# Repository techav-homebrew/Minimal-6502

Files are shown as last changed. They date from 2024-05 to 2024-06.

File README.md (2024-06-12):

# Minimal-6502
Minimal 6502 SBC based on Grant Searle's 8-chip 6502 computer and laid out as a 4x3" PCB.

Modifications from Grant Searle's design include:
- Addition of expansion header
- Changed clock from crystal to standard TTL can oscillator
- Added option for USB for serial & power via FTDI
- Reassembled software for 8kB EEPROM instead of 16kB EPROM because 27128 EPROM is not readily available (PCB still supports 27128)

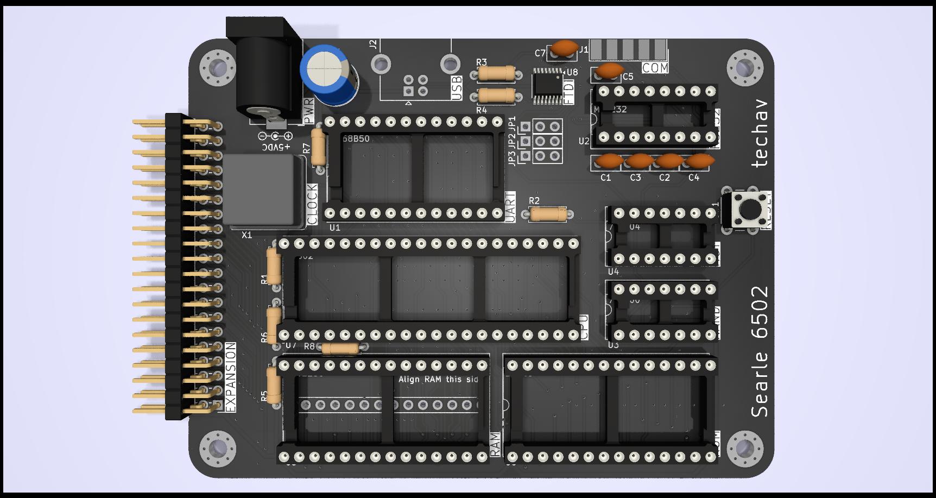
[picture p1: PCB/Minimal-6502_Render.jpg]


## Assembly Notes
Part U5, 32kB SRAM, can be either a 7.5mm or 14.5mm width part. If using a 7.5mm package, it should be aligned as indicated on the side closest to the CPU. 

Computer can be assembled with either an RS-232 serial port for use with a traditional terminal or USB serial adapter for use with a modern computer as a terminal. Parts related to each option are listed below.

### RS-232 DE-9 Serial
- J1 - DE-9 connector
- U2 - MAX232 RS-232 level shifter
- C1, C2, C3, C4 - 100nF capacitor
- J3 - 2.1mm barrel power connector

### USB Serial
- J2 - USB-B connector
- U8 - FTDI FT230X
- R3, R4 - 26-Ohm resistor

## Usage Notes
The computer should be powered by USB or via the barrel connector, not both. There is no on-board voltage regulation, so if the barrel connector is used, then the computer should be powered by a regulated 5V power supply. 

Serial bit rate is 115200, and backspace should be configured for **Control-H** (PuTTY defaults to **Control-?**)

When using a terminal emulator via USB, it may be necessary to press Reset to display the Cold Start prompt. 

If no size is entered on the memory size prompt, then the computer will attempt to determine the installed memory size.

## Expansion Port Header Pinout
1. +5V
2. +5V
3. +5V
4. +5V
5. D0
6. A0
7. D1
8. A1
9. D2
10. A2
11. D3
12. A3
13. D4
14. A4
15. D5
16. A5
17. D6
18. A6
19. D7
20. A7
21. R/W#
22. A8
23. READ#
24. A9
25. WRITE#
26. A10
27. NMI#
28. A11
29. RDY
30. A12
31. IRQ#
32. A13
33. [Not Connected]
34. A14
35. Phi2
36. A15
37. Ground
38. Ground
39. Ground
40. Ground

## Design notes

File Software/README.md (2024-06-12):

The contents of this folder were downloaded from http://searle.x10host.com/6502/Simple6502.html

utility bin2hex from https://www.sydneysmith.com/wordpress/bin2hex/

CHANGELOG
2024/06/11 techav:
- modified osi_bas.s & osi_bas.cfg for 8kB ROM (28C64) instead of 16kB ROM (27128) because the latter is harder to find these days.
- added bin2hex step to assemble.bat to generate Intel Hex file from assembled binary

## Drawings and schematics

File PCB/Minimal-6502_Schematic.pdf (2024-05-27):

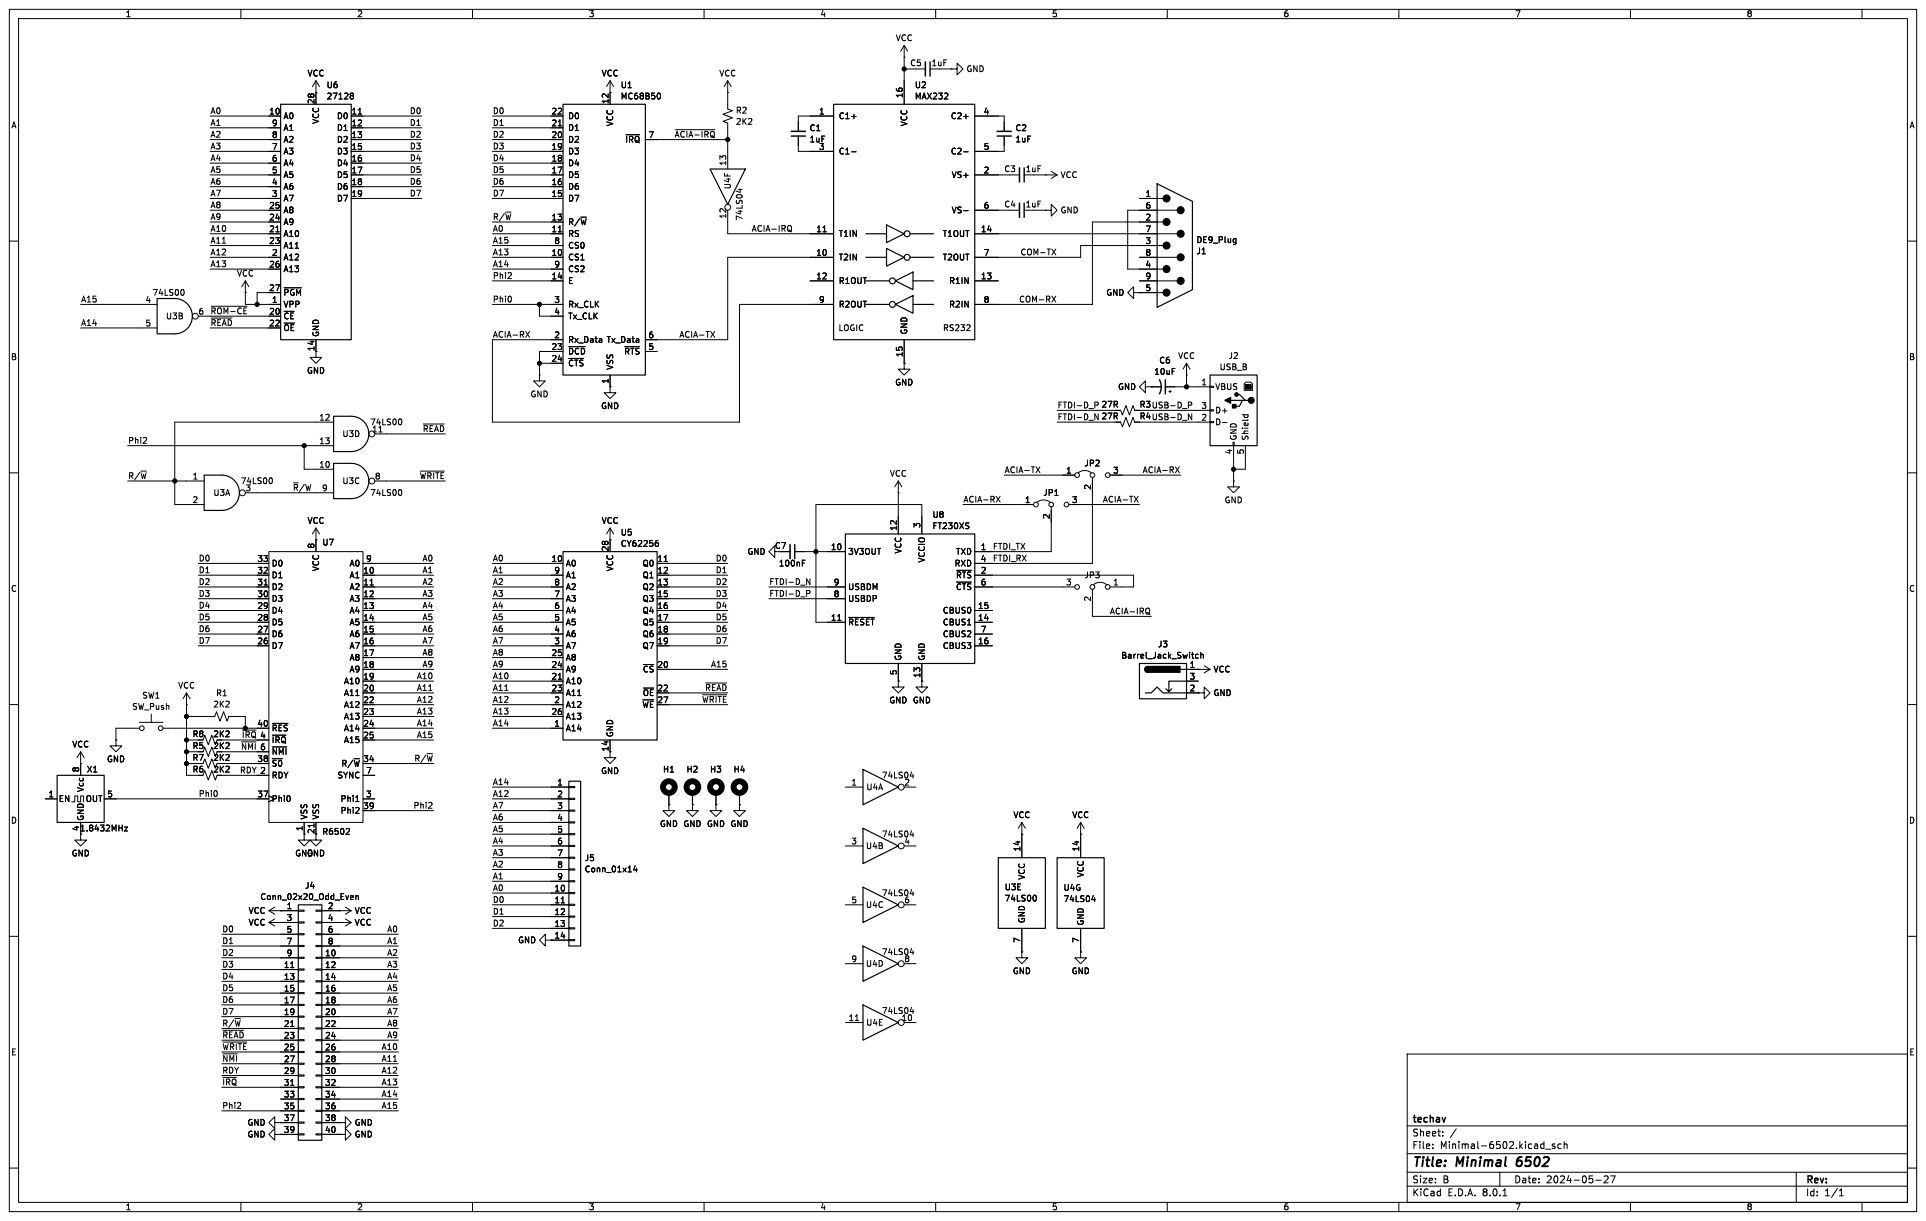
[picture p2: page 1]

COM-RX COM-TX

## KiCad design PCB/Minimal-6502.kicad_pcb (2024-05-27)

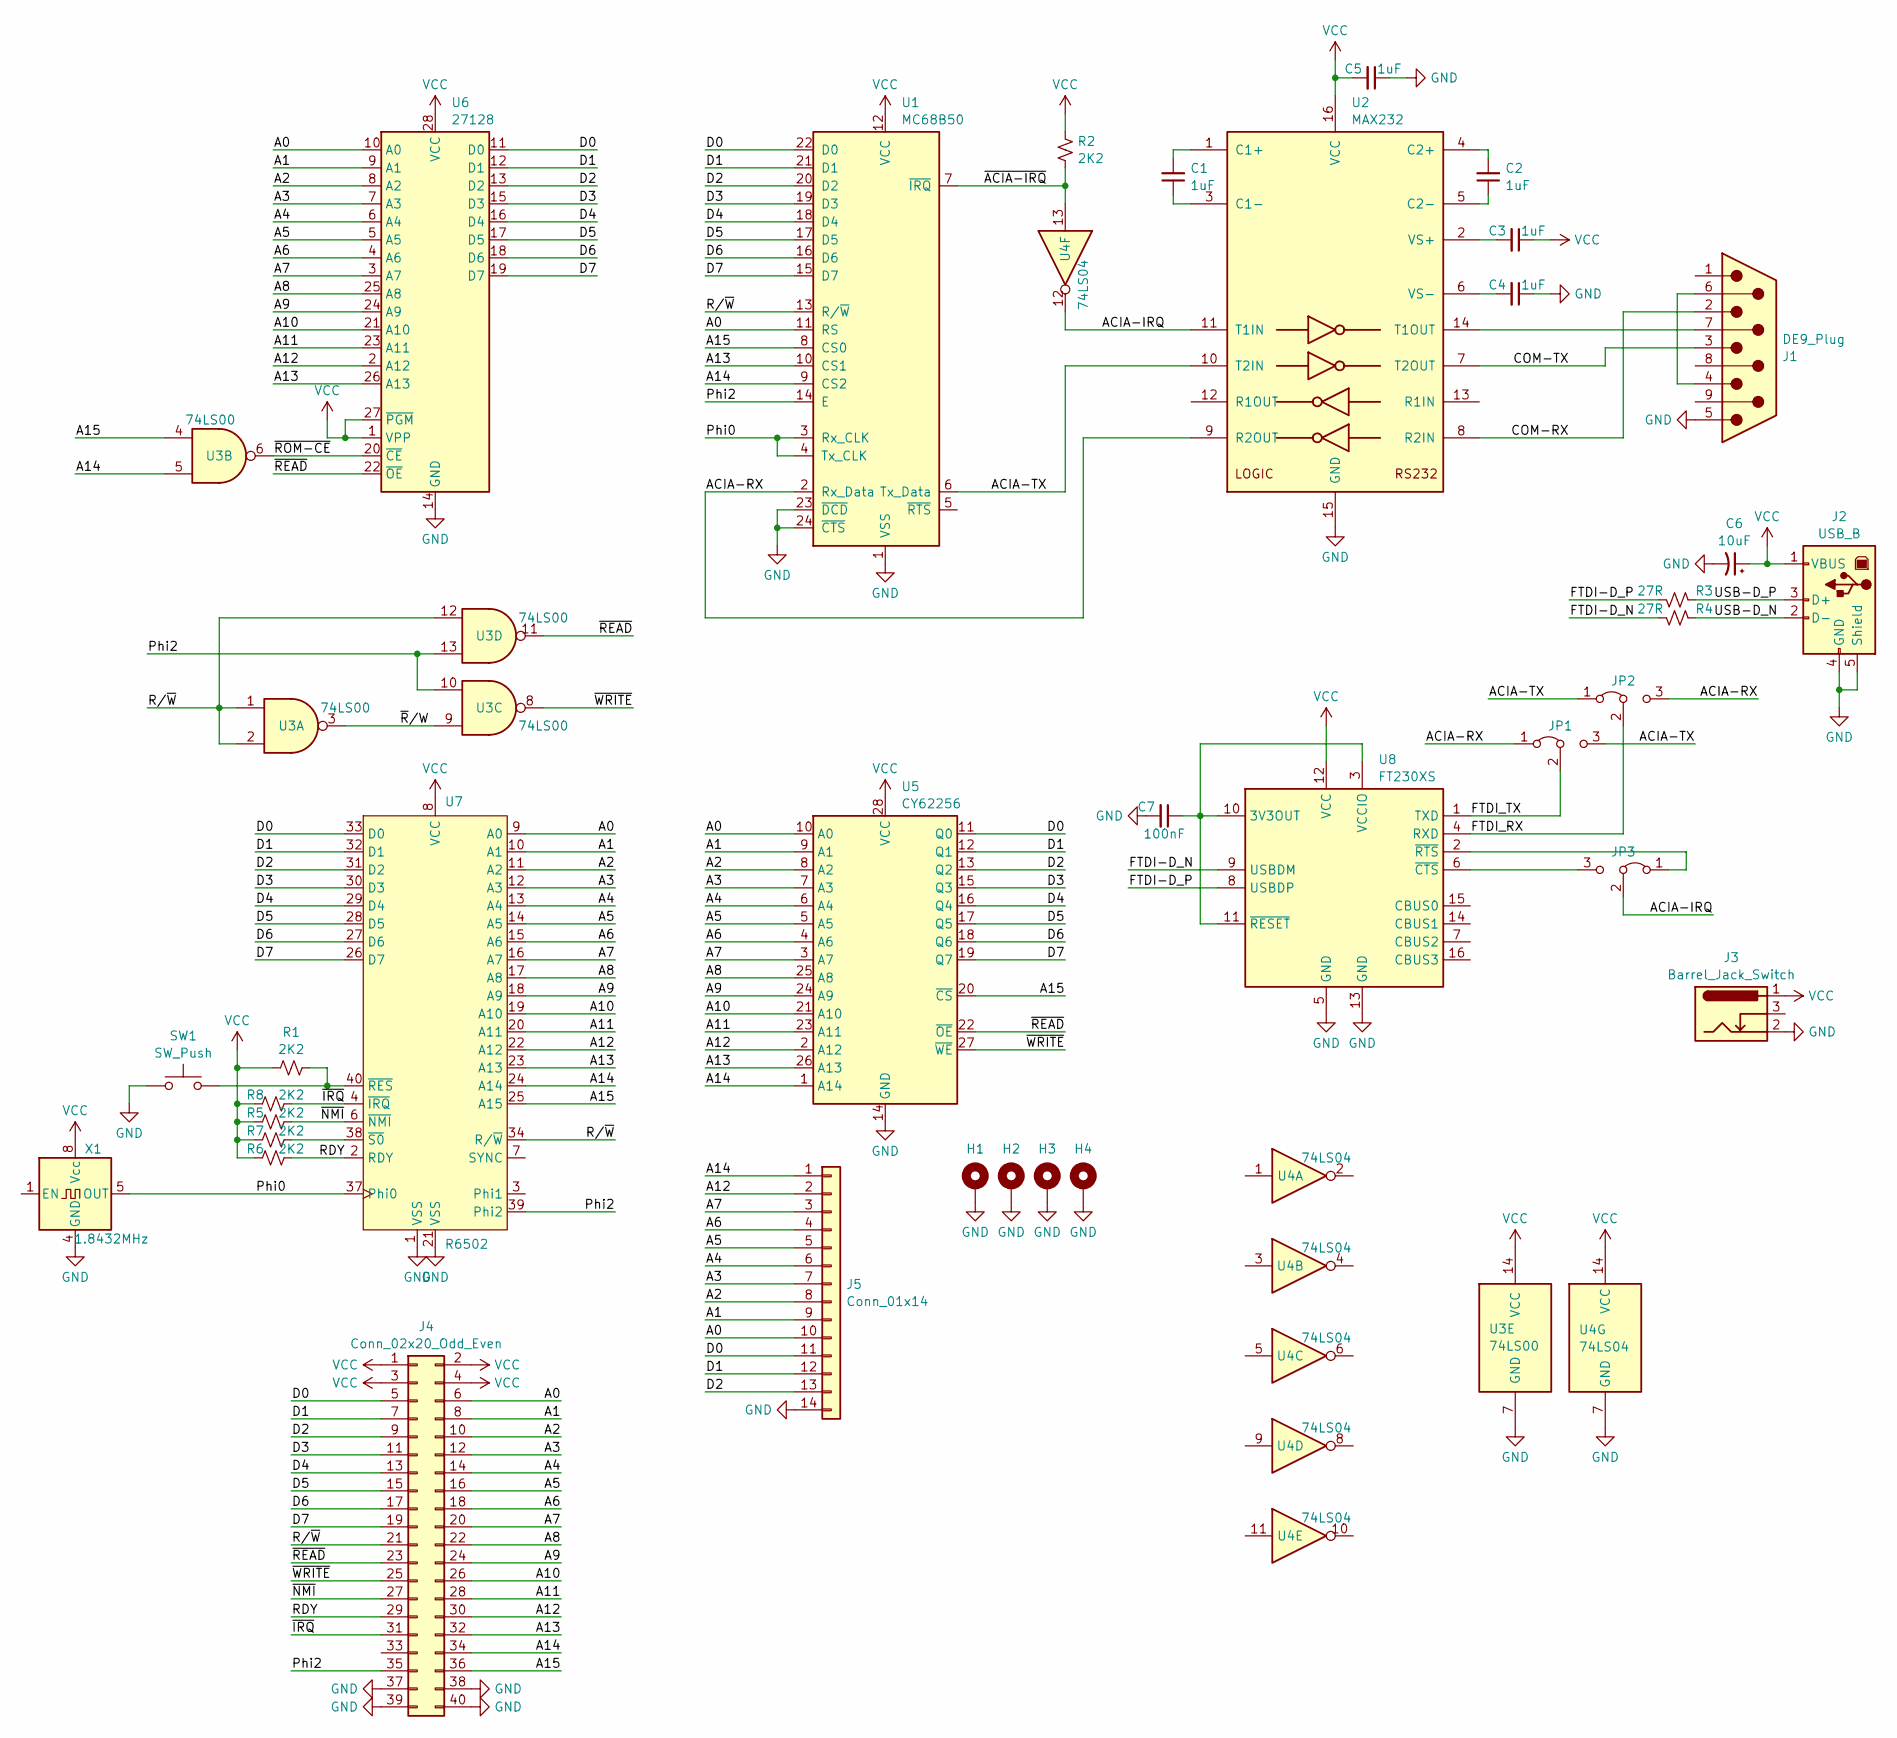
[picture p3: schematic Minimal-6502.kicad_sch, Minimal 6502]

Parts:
C1, C2, C3, C4, C5: 1uF; C_Disc_D5.0mm_W2.5mm_P2.50mm
C6: 10uF; CP_Radial_D8.0mm_P5.00mm
C7: 100nF; C_Disc_D5.0mm_W2.5mm_P2.50mm
H1, H2, H3, H4: MountingHole_Pad; MountingHole_3.2mm_M3_Pad_Via
J1: DE9_Plug; DSUB-9_Male_EdgeMount_P2.77mm
J2: USB_B; USB_B_OST_USB-B1HSxx_Horizontal
J3: Barrel_Jack_Switch; BarrelJack_Horizontal
J4: Conn_02x20_Odd_Even; PinHeader_2x20_P2.54mm_Horizontal
J5: Conn_01x14; PinHeader_1x14_P2.54mm_Vertical
JP1, JP2, JP3: Jumper_3_Bridged12; PinHeader_1x03_P2.54mm_Vertical
R1, R2, R5, R6, R7, R8: 2K2; R_Axial_DIN0207_L6.3mm_D2.5mm_P7.62mm_Horizontal
R3, R4: 27R; R_Axial_DIN0207_L6.3mm_D2.5mm_P7.62mm_Horizontal
SW1: SW_Push; SW_PUSH_6mm
U1: MC68B50; DIP-24_W15.24mm_Socket
U2: MAX232; DIP-16_W7.62mm_Socket
U3: 74LS00; DIP-14_W7.62mm_Socket
U4: 74LS04; DIP-14_W7.62mm_Socket
U5: CY62256; DIP-28_W15.24mm_Socket
U6: 27128; DIP-28_W15.24mm_Socket
U7: R6502; DIP-40_W15.24mm_Socket
U8: FT230XS; SSOP-16_3.9x4.9mm_P0.635mm
X1: 1.8432MHz; Oscillator_DIP-8

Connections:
/A0: J4.6, J5.10, U1.11 (RS), U5.10 (A0), U6.10 (A0), U7.9 (A0)
/A1: J4.8, J5.9, U5.9 (A1), U6.9 (A1), U7.10 (A1)
/A2: J4.10, J5.8, U5.8 (A2), U6.8 (A2), U7.11 (A2)
/A3: J4.12, J5.7, U5.7 (A3), U6.7 (A3), U7.12 (A3)
/A4: J4.14, J5.6, U5.6 (A4), U6.6 (A4), U7.13 (A4)
/A5: J4.16, J5.5, U5.5 (A5), U6.5 (A5), U7.14 (A5)
/A6: J4.18, J5.4, U5.4 (A6), U6.4 (A6), U7.15 (A6)
/A7: J4.20, J5.3, U5.3 (A7), U6.3 (A7), U7.16 (A7)
/A8: J4.22, U5.25 (A8), U6.25 (A8), U7.17 (A8)
/A9: J4.24, U5.24 (A9), U6.24 (A9), U7.18 (A9)
/A10: J4.26, U5.21 (A10), U6.21 (A10), U7.19 (A10)
/A11: J4.28, U5.23 (A11), U6.23 (A11), U7.20 (A11)
/A12: J4.30, J5.2, U5.2 (A12), U6.2 (A12), U7.22 (A12)
/A13: J4.32, U1.10 (CS1), U5.26 (A13), U6.26 (A13), U7.23 (A13)
/A14: J4.34, J5.1, U1.9 (CS2), U3.5, U5.1 (A14), U7.24 (A14)
/A15: J4.36, U1.8 (CS0), U3.4, U5.20 (~CS), U7.25 (A15)
/ACIA-IRQ: JP3.2 (C), U2.11 (T1IN), U4.12
/ACIA-RX: JP1.1 (A), JP2.3 (B), U1.2 (Rx_Data), U2.9 (R2OUT)
/ACIA-TX: JP1.3 (B), JP2.1 (A), U1.6 (Tx_Data), U2.10 (T2IN)
/COM-RX: J1.2, U2.8 (R2IN)
/COM-TX: J1.3, U2.7 (T2OUT)
/D0: J4.5, J5.11, U1.22 (D0), U5.11 (Q0), U6.11 (D0), U7.33 (D0)
/D1: J4.7, J5.12, U1.21 (D1), U5.12 (Q1), U6.12 (D1), U7.32 (D1)
/D2: J4.9, J5.13, U1.20 (D2), U5.13 (Q2), U6.13 (D2), U7.31 (D2)
/D3: J4.11, U1.19 (D3), U5.15 (Q3), U6.15 (D3), U7.30 (D3)
/D4: J4.13, U1.18 (D4), U5.16 (Q4), U6.16 (D4), U7.29 (D4)
/D5: J4.15, U1.17 (D5), U5.17 (Q5), U6.17 (D5), U7.28 (D5)
/D6: J4.17, U1.16 (D6), U5.18 (Q6), U6.18 (D6), U7.27 (D6)
/D7: J4.19, U1.15 (D7), U5.19 (Q7), U6.19 (D7), U7.26 (D7)
/FTDI-D_N: R4.1, U8.9 (USBDM)
/FTDI-D_P: R3.1, U8.8 (USBDP)
/FTDI_RX: JP2.2 (C), U8.4 (RXD)
/FTDI_TX: JP1.2 (C), U8.1 (TXD)
/Phi0: U1.3 (Rx_CLK), U1.4 (Tx_CLK), U7.37 (Phi0), X1.5 (OUT)
/Phi2: J4.35, U1.14 (E), U3.10, U3.13, U7.39 (Phi2)
/RDY: J4.29, R6.1, U7.2 (RDY)
/R/~W: J4.21, U1.13 (R/~W), U3.1, U3.2, U3.12, U7.34 (R/~W)
/USB-D_N: J2.2 (D-), R4.2
/USB-D_P: J2.3 (D+), R3.2
/~ACIA-IRQ: R2.2, U1.7 (~IRQ), U4.13
/~IRQ: J4.31, R8.1, U7.4 (~IRQ)
/~NMI: J4.27, R5.1, U7.6 (~NMI)
/~READ: J4.23, U3.11, U5.22 (~OE), U6.22 (~OE)
/~ROM-CE: U3.6, U6.20 (~CE)
/~R/W: U3.3, U3.9
/~WRITE: J4.25, U3.8, U5.27 (~WE)
GND: C4.1, C5.1, C6.2, C7.2, H1.1, H2.1, H3.1, H4.1, J1.5, J2.4 (GND), J2.5 (Shield), J3.2, J4.37, J4.38, J4.39, J4.40, J5.14, SW1.1, U1.1 (VSS), U1.23 (~DCD), U1.24 (~CTS), U2.15 (GND), U3.7 (GND), U4.7 (GND), U5.14 (GND), U6.14 (GND), U7.1 (VSS), U7.21 (VSS), U8.5 (GND), U8.13 (GND), X1.4 (GND)
unnamed: J1.4, J1.6
unnamed: JP3.1 (A), U8.2 (~RTS)
unnamed: JP3.3 (B), U8.6 (~CTS)
unnamed: C1.2, U2.1 (C1+)
unnamed: C1.1, U2.3 (C1-)
unnamed: C2.2, U2.4 (C2+)
unnamed: C2.1, U2.5 (C2-)
unnamed: J1.7, U2.14 (T1OUT)
unnamed: C3.2, U2.2 (VS+)
unnamed: C4.2, U2.6 (VS-)
unnamed: R1.1, SW1.2, U7.40 (~RES)
unnamed: R7.1, U7.38 (~S0)
unnamed: C7.1, U8.3 (VCCIO), U8.10 (3V3OUT), U8.11 (~RESET)
VCC: C3.1, C5.2, C6.1, J2.1 (VBUS), J3.1, J4.1, J4.2, J4.3, J4.4, R1.2, R2.1, R5.2, R6.2, R7.2, R8.2, U1.12 (VCC), U2.16 (VCC), U3.14 (VCC), U4.14 (VCC), U5.28 (VCC), U6.1 (VPP), U6.27 (~PGM), U6.28 (VCC), U7.8 (VCC), U8.12 (VCC), X1.8 (Vcc)

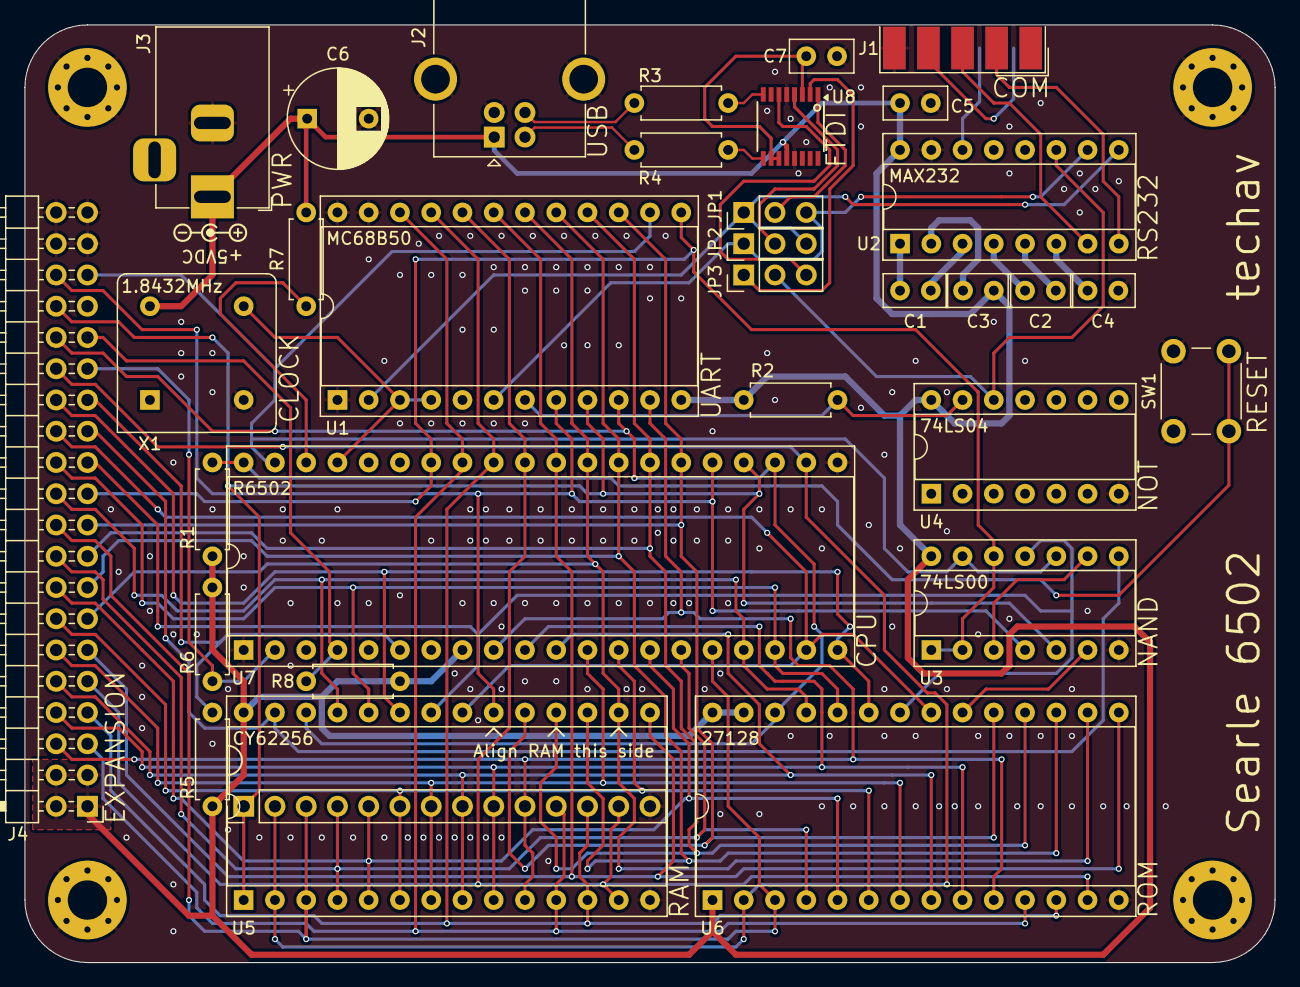
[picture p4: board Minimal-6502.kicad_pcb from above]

Board: 2 copper layers, 101.6 x 76.2 mm, 37 parts (0 on the bottom side), 61 nets.

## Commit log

2024-05-27 Initial PCB
    [Minimal-6502-B_Cu.gbl, Minimal-6502-B_Mask.gbs, Minimal-6502-B_Paste.gbp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]
2024-06-11 Searle ROM code
    [osi_bas.cfg]
2024-06-12 Target 8kB ROM
    [osi_bas.cfg]
